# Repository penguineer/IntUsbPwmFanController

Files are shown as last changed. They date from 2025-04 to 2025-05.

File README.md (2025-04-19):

# PWM Fan Controller with Internal USB connection

> Controller for PWM-based fans using the internal USB 2.0 header

I have an NVIDIA server GPU which relies on external fans and uses the
`nvidia-smi` cli to report its temperature. In addition, my mainboard
does not allow for fan speed control under
Linux.

As this is my workstation setup and I do not want the fans running at
full speed all the time, I needed a controller to set the fan speed from
software, which easily integrates into my case.

This controller is plugged into an internal USB 2.0 header and offers
the 4-pin PWM header to connect fans.

## License



This work is licensed under
a [Creative Commons Attribution-ShareAlike 4.0 International License](http://creativecommons.org/licenses/by-sa/4.0/).

BY: Stefan Haun (mail at tuxathome.de)

See [LICENSE.txt](LICENSE.txt) for details.

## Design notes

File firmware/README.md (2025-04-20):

# PWM Fan Controller with Internal USB connection - Firmware

> Firmware for the PWM Fan Controller

Please refer to the [project README](../README.md) for further information.

## API

The MCU pin assignment is as follows:

* `PA1` - SDA
* `PA2` - SCL
* `PA3` - PWM output
* `PA6` - Tachometer signal input
* `PA7` - `SLEEP#` input, active low

The firmware exposes an I2C API for the PWM Fan Controller with the following commands:

* `TWI_CMD_GET_ID` (read): Get the serial number of the ATtiny202 device. Returns the serial number as a 4-byte array.
* `TWI_CMD_SET_PWM` (write): Set the PWM value using an 1-byte parameter, where `0x00` is 0%, aka off, and `0xFF` is
  100%, aka full speed.
* `TWI_CMD_GET_TACHO` (read): Get the most recent tachometer measurement in RPM as a 2-byte array.

Pin `PA7` acts as a suspend pin. If the pin is pulled low, the firmware will enter a low-power mode. The firmware will
wake up when the pin is pulled high again.

## Architecture

The firmware is designed to run on
the [ATtiny202](https://ww1.microchip.com/downloads/en/DeviceDoc/ATtiny202-402-AVR-MCU-with-Core-Independent-Peripherals_and-picoPower-40001969A.pdf)
microcontroller. It uses the I2C protocol for communication with
an [FTDI201XS](https://www.mouser.de/datasheet/2/163/DS_FT201X-3173.pdf) host.

The code makes heavy use of interrupts and the event system to handle all required tasks on a small MCU, so that the
main loop solely consists of setup code.

### TWI handling

TWI communication is handled using the *ATtiny202 TWI*
peripheral with small RX and TX buffers for multibyte transfers. Depending on the command received, a matching handler
function is called.

### PWM generation

The PWM signal is generated using
the *ATtiny202 Timer/Counter TCA*.
The frequency is set to 25 kHz, according to the specifications for PC fans (c.f. [Noctua PWM specifications
white paper](https://noctua.at/pub/media/wysiwyg/Noctua_PWM_specifications_white_paper.pdf)).

### Tachometer measurement

The tachometer pulses are counted using the *ATtiny202 Timer/Counter TCB*.
Using the *Event System*, the TCB is configured to trigger on the rising edge of the tachometer signal on pin `PA6`.

The *ATtiny202 RTC* is configured to generate an interrupt once per second. The interrupt handler reads the TCB
counter value and resets it. The counter value is then converted to RPM and stored in a buffer, which can be read by the
TWI handler.

### Low-power mode handling

When the `SLEEP#` pin is pulled low, the firmware enters a low-power mode. The PWM signal is turned off and tachometer
measurements is disabled.

The firmware will wake up when the pin is pulled high again, re-setting the PWM duty cycle to the last set value and
re-enabling the tachometer measurement. Please note that the first two seconds of RMP measurement after waking up are
not accurate, as the FAN needs to spin up first and the measurement has been reset to zero.

## License

The firmware is licensed under the [MIT License](LICENSE.txt). See the [LICENSE.txt](LICENSE.txt) file for details.

© 2025 Stefan Haun and contributors

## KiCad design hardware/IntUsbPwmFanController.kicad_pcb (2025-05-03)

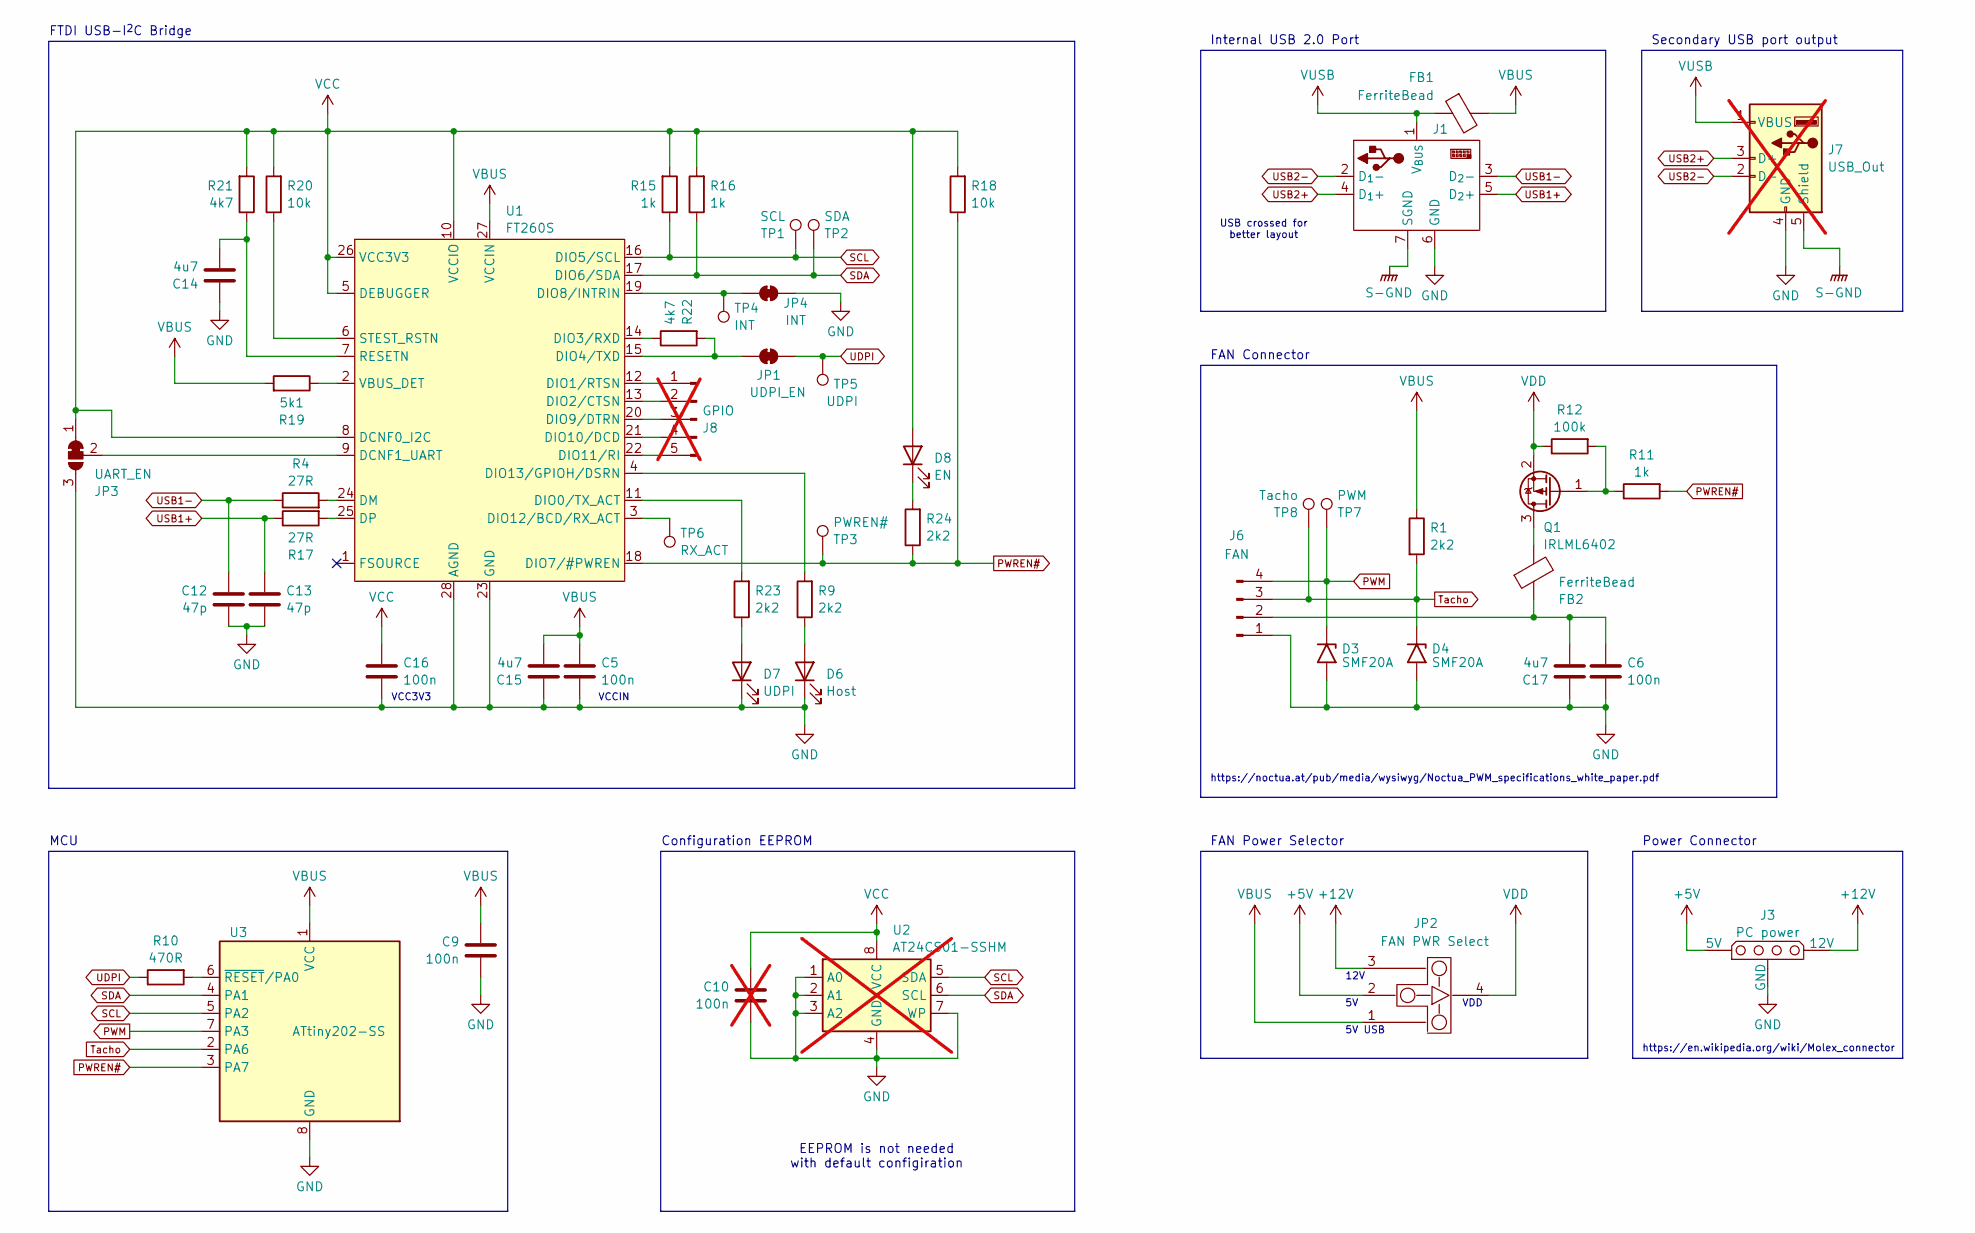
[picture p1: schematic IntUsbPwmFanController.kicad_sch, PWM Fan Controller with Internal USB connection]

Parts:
C5, C6, C9, C16: 100n; C_0603_1608Metric_Pad1.08x0.95mm_HandSolder; Mouser No 963-TMK107BJ104MA-T
C10: 100n; C_0603_1608Metric_Pad1.08x0.95mm_HandSolder; Mouser No 963-TMK107BJ104MA-T; not fitted
C12, C13: 47p; C_0603_1608Metric_Pad1.08x0.95mm_HandSolder; Mouser No 80-C0603C470K4HACTU
C14, C15, C17: 4u7; C_0603_1608Metric_Pad1.08x0.95mm_HandSolder; Mouser No 963-TMK107BJ104MA-T
D3, D4: SMF20A; D_SMF; LCSC C151295
D6: Host; LED_0603_1608Metric_Pad1.05x0.95mm_HandSolder; Mouser No 720-LTQ39GQ1S22515
D7: UDPI; LED_0603_1608Metric_Pad1.05x0.95mm_HandSolder; Mouser No 630-HSMC-C130
D8: EN; LED_0603_1608Metric_Pad1.05x0.95mm_HandSolder; Mouser No 720-LTQ39GQ1S22515
FB1, FB2: FerriteBead; R_0603_1608Metric_Pad0.98x0.95mm_HandSolder; Mouser No 81-BLM18SG221TZ1D
J1: Internal USB 2.0 Header Default
J3: PC power; Molex 8981 Vertical
J6: FAN; FanPinHeader_1x04_P2.54mm_Vertical
J7: USB_Out; USB_A_Molex_105057_Vertical; not fitted
J8: GPIO; PinHeader_1x05_P2.54mm_Vertical; not fitted
JP1: UDPI_EN; SolderJumper-2_P1.3mm_Bridged_RoundedPad1.0x1.5mm
JP2: FAN PWR Select; ThreeWayJumper
JP3: UART_EN; SolderJumper-3_P1.3mm_Bridged12_RoundedPad1.0x1.5mm
JP4: INT; SolderJumper-2_P1.3mm_Bridged_RoundedPad1.0x1.5mm
Q1: IRLML6402; SOT-23
R1, R9, R23, R24: 2k2; R_0603_1608Metric_Pad0.98x0.95mm_HandSolder
R4, R17: 27R; R_0603_1608Metric_Pad0.98x0.95mm_HandSolder
R10: 470R; R_0603_1608Metric_Pad0.98x0.95mm_HandSolder
R11, R15, R16: 1k; R_0603_1608Metric_Pad0.98x0.95mm_HandSolder
R12: 100k; R_0603_1608Metric_Pad0.98x0.95mm_HandSolder
R18, R20: 10k; R_0603_1608Metric_Pad0.98x0.95mm_HandSolder
R19: 5k1; R_0603_1608Metric_Pad0.98x0.95mm_HandSolder
R21, R22: 4k7; R_0603_1608Metric_Pad0.98x0.95mm_HandSolder
TP1: SCL; TestPoint_Pad_D1.0mm
TP2: SDA; TestPoint_Pad_D1.0mm
TP3: PWREN#; TestPoint_Pad_D1.0mm
TP4: INT; TestPoint_Pad_D1.0mm
TP5: UDPI; TestPoint_Pad_D1.0mm
TP6: RX_ACT; TestPoint_Pad_D1.0mm
TP7: PWM; TestPoint_Pad_D1.0mm
TP8: Tacho; TestPoint_Pad_D1.0mm
U1: FT260S; TSSOP-28_4.4x9.7mm_P0.65mm
U2: AT24CS01-SSHM; SOIC-8_3.9x4.9mm_P1.27mm; Mouser No 556-AT24CS01-SSHM-T; not fitted
U3: ATtiny202-SS; SOIC-8_3.9x4.9mm_P1.27mm

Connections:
+5V: J3.4 (5V), JP2.2 (OPT2)
+12V: J3.1 (12V), JP2.3 (OPT3)
GND: C5.2, C6.2, C9.2, C10.2, C12.2, C13.2, C14.1, C15.1, C16.2, C17.1, D3.2 (A2), D4.2 (A2), D6.1 (K), D7.1 (K), J1.6 (GND), J3.23 (GND), J6.1, J7.4 (GND), JP3.3 (B), JP4.2 (B), U1.23 (GND), U1.28 (AGND), U2.1 (A0), U2.2 (A1), U2.3 (A2), U2.4 (GND), U2.7 (WP), U3.8 (GND)
unnamed: D6.2 (A), R9.1
unnamed: D7.2 (A), R23.1
unnamed: D8.1 (K), R24.2
unnamed: C6.1, C17.2, FB2.1, J6.2
unnamed: J8.1, U1.12 (DIO1/RTSN)
unnamed: J8.2, U1.13 (DIO2/CTSN)
unnamed: J8.3, U1.20 (DIO9/DTRN)
unnamed: J8.4, U1.21 (DIO10/DCD)
unnamed: J8.5, U1.22 (DIO11/RI)
unnamed: JP1.1 (A), R22.2, U1.15 (DIO4/TXD)
unnamed: JP3.2 (C), U1.9 (DCNF1_UART)
unnamed: JP4.1 (A), TP4.1, U1.19 (DIO8/INTRIN)
unnamed: FB2.2, Q1.3 (D)
unnamed: Q1.1 (G), R11.1, R12.2
unnamed: R23.2, U1.11 (DIO0/TX_ACT)
unnamed: R22.1, U1.14 (DIO3/RXD)
unnamed: TP6.1, U1.3 (DIO12/BCD/RX_ACT)
unnamed: R9.2, U1.4 (DIO13/GPIOH/DSRN)
unnamed: R4.2, U1.24 (DM)
unnamed: R17.2, U1.25 (DP)
unnamed: C14.2, R21.1, U1.7 (RESETN)
unnamed: R20.1, U1.6 (STEST_RSTN)
unnamed: R19.1, U1.2 (VBUS_DET)
unnamed: R10.2, U3.6 (~RESET/PA0)
PWM: D3.1 (A1), J6.4, TP7.1, U3.7 (PA3)
PWREN#: R11.2, R18.1, R24.1, TP3.1, U1.18 (DIO7/#PWREN), U3.3 (PA7)
S-GND: J1.7 (SGND), J7.5 (Shield)
SCL: R15.1, TP1.1, U1.16 (DIO5/SCL), U2.5 (SDA), U3.5 (PA2)
SDA: R16.1, TP2.1, U1.17 (DIO6/SDA), U2.6 (SCL), U3.4 (PA1)
Tacho: D4.1 (A1), J6.3, R1.2, TP8.1, U3.2 (PA6)
UDPI: JP1.2 (B), R10.1, TP5.1
USB1+: C13.1, J1.5 (D_{2}+), R17.1
USB1-: C12.1, J1.3 (D_{2}-), R4.1
USB2+: J1.4 (D_{1}+), J7.3 (D+)
USB2-: J1.2 (D_{1}-), J7.2 (D-)
VBUS: C5.1, C9.1, C15.2, FB1.2, JP2.1 (OPT1), R1.1, R19.2, U1.27 (VCCIN), U3.1 (VCC)
VCC: C10.1, C16.1, D8.2 (A), JP3.1 (A), R15.2, R16.2, R18.2, R20.2, R21.2, U1.5 (DEBUGGER), U1.8 (DCNF0_I2C), U1.10 (VCCIO), U1.26 (VCC3V3), U2.8 (VCC)
VDD: JP2.4 (SEL), Q1.2 (S), R12.1
VUSB: FB1.1, J1.1 (V_{BUS}), J7.1 (VBUS)

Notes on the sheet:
Secondary USB port output
https://en.wikipedia.org/wiki/Molex_connector
Power Connector
USB crossed for better layout
EEPROM is not needed with default configiration
VDD
VCCIN
Internal USB 2.0 Port
5V USB
FAN Connector
12V
MCU
FAN Power Selector
Configuration EEPROM
https://noctua.at/pub/media/wysiwyg/Noctua_PWM_specifications_white_paper.pdf
FTDI USB-I^{2}C Bridge
VCC3V3

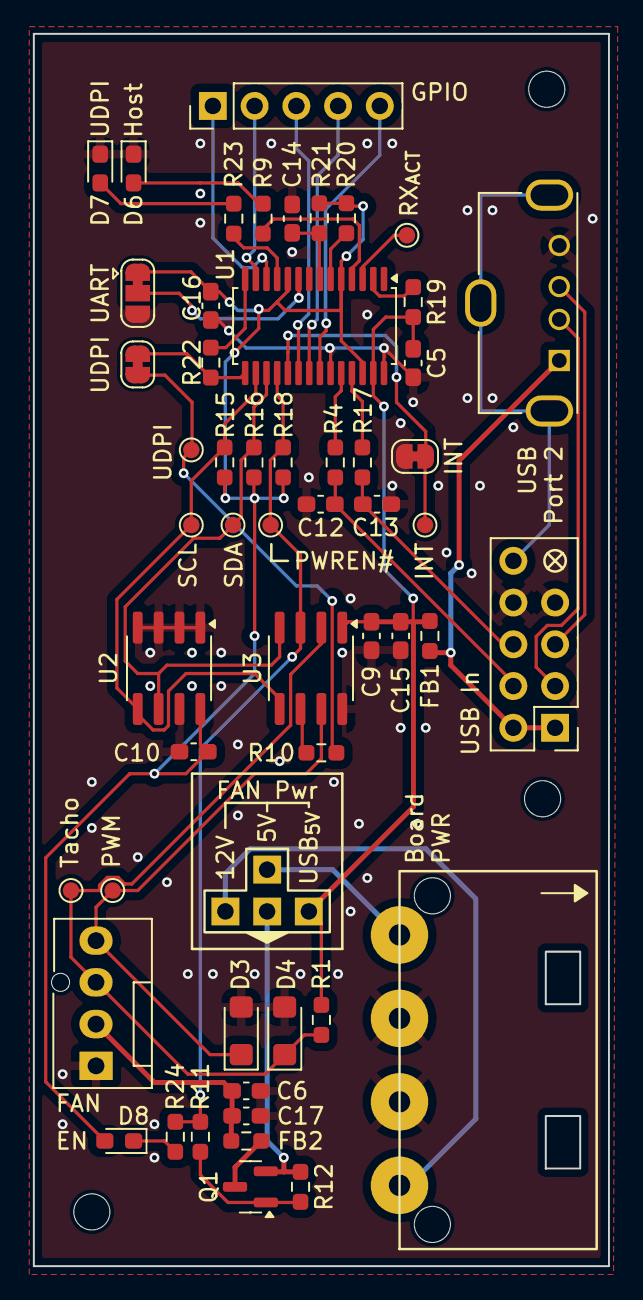
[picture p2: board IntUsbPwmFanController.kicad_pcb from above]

Board: 2 copper layers, 35.0 x 75.0 mm, 54 parts (0 on the bottom side), 42 nets.

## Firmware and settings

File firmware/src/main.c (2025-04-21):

#include <stddef.h>
#include <avr/io.h>
#include <avr/interrupt.h>
#include <avr/sleep.h>

#define TWI_SLAVE_ADDRESS 0x42

/* TWI command "Get ID"
 *
 * This command returns the unique chip ID (4 bytes).
 */
#define TWI_CMD_GET_ID    0x01
/* TWI command "Set PWM"
 *
 * This command sets the target PWM value (1 byte).
 */
#define TWI_CMD_SET_PWM   0x02
/* TWI command "Get Tacho"
 *
 * This command returns the most recent completed tachometer measurement (2 bytes).
 *
 * Please note that there is a delay between setting the PWM value and retrieving a matching tachometer measurement.
 */
#define TWI_CMD_GET_TACHO 0x03

/***** Global variables *****/

uint8_t pwm_target = 0; // Target PWM value
uint16_t tacho_rpm = 0; // Most recent tacho measurement

/***** PWM *****/

// Assumes a prescaler of 8 and a frequency of 25 kHz
#define PWM_PREBUF ((F_CPU / (8 * 25000)) - 1)

void TCA_init_pwm(void) {
    // Configure PA3 as output
    PORTA.DIRSET = PIN3_bm; // Set PA3 as output

    // TCA0 WO[1] routes to PA3

    // Set TCA0 to single-slope PWM mode
    TCA0.SINGLE.CTRLB = TCA_SINGLE_WGMODE_SINGLESLOPE_gc | TCA_SINGLE_CMP1EN_bm; // Enable WO1 (PA3)

    // Set the period
    TCA0.SINGLE.PER = PWM_PREBUF;

    // Set the compare value for 0% duty cycle
    TCA0.SINGLE.CMP1 = 0; // 0% duty cycle

    // Enable the TCA0 clock with a prescaler of 8
    TCA0.SINGLE.CTRLA = TCA_SINGLE_CLKSEL_DIV8_gc | TCA_SINGLE_ENABLE_bm;
}

void update_target_pwm(const uint8_t duty_cycle_param) {
    // Store the setting
    pwm_target = duty_cycle_param;

    // Perform the calculation in a 32-bit space to avoid wrapping/clipping
    const uint32_t temp = (uint32_t) PWM_PREBUF * duty_cycle_param;
    // Scale back to the correct range
    TCA0.SINGLE.CMP1 = temp >> 8;
}

/***** Tacho *****/

void PA6_enable_edge_sensing(void) {
    // Enable sensing on rising edge
    PORTA.PIN6CTRL = PORT_ISC_RISING_gc;
}

void PA6_disable_edge_sensing(void) {
    // Disable sensing
    PORTA.PIN6CTRL = 0;
}

void TCB_init_tacho_counter(void) {
    // Configure PA6 as input
    PORTA.DIRCLR = PIN6_bm; // Set PA6 as input
    PA6_enable_edge_sensing();

    // Configure Event System to route PA6 to TCB0
    EVSYS.ASYNCCH0 = EVSYS_ASYNCCH0_PORTA_PIN6_gc; // Pin PA6
    EVSYS.ASYNCUSER0 = EVSYS_ASYNCUSER0_ASYNCCH0_gc; // route to TCB0

    // Configure TCB0 in event counting mode
    TCB0.CTRLA = TCB_CLKSEL_CLKDIV1_gc | TCB_ENABLE_bm; // Enable TCB0 with no prescaler
    TCB0.CTRLB = TCB_CNTMODE_FRQ_gc; // Frequency measurement mode (event counting)

    // Clear the counter
    TCB0.CNT = 0;
}

uint16_t TCB_get_and_reset_count(void) {
    // Disable edge sensing to prevent race conditions
    PA6_disable_edge_sensing();

    // Read the current count
    const uint16_t count = TCB0.CNT;
    // Clear the counter
    TCB0.CNT = 0;

    // Enable edge sensing
    PA6_enable_edge_sensing();

    // Return the current counter value
    return count;
}

void RTC_init(void) {
    // Wait until RTC is not busy
    while (RTC.STATUS > 0)
        /* busy wait */;

    // Initialize RTC function
    // (ATtiny 202 Datasheet 22.3)

    // Configure RTC clock source to use the 1 kHz internal oscillator
    RTC.CLKSEL = RTC_CLKSEL_INT1K_gc;

    // Set the period to 1000 (1 second with 1 kHz clock)
    RTC.PER = 1000;

    // Enable the overflow (OVF) interrupt
    RTC.INTCTRL = RTC_OVF_bm;

    // Configure the prescaler to divide by 1 and enable the RTC
    RTC.CTRLA = RTC_PRESCALER_DIV1_gc | RTC_RTCEN_bm;

    // Clear any existing interrupt flags
    RTC.INTFLAGS = RTC_OVF_bm;
}

void RTC_reset(void) {
    // Wait until RTC is not busy
    while (RTC.STATUS > 0)
        /* busy wait */;

    // Reset the RTC counter
    RTC.CNT = 0;
}

ISR(RTC_CNT_vect) {
    // We are reading the TCB0 counter once per second
    const uint16_t revolutions_per_second = TCB_get_and_reset_count();

    // Convert to RPM according to specification
    // See https://noctua.at/pub/media/wysiwyg/Noctua_PWM_specifications_white_paper.pdf for details.
    // There are two pulses per revolution.
    const uint16_t rpm = revolutions_per_second * 60 >> 1;

    // Atomic store
    cli();
    tacho_rpm = rpm;
    sei();

    // Clear the overflow interrupt flag
    RTC.INTFLAGS = RTC_OVF_bm;
}

/***** TWI Core *****/

void TWI_slave_init(void) {
    // Configure SCL (PA2) and SDA (PA1) as inputs
    PORTA.DIRCLR = PIN2_bm | PIN1_bm; // leaves other pins unchanged

    // Enable internal pull-ups on SCL (PA2) and SDA (PA1)
    PORTA.PIN2CTRL |= PORT_PULLUPEN_bm;
    PORTA.PIN1CTRL |= PORT_PULLUPEN_bm;

    // Set the slave address
    TWI0.SADDR = TWI_SLAVE_ADDRESS << 1; // Shifted left by 1 for 7-bit addressing

    // Enable TWI Slave, enable stop interrupt, and enable data interrupt
    TWI0.SCTRLA = TWI_ENABLE_bm | TWI_PIEN_bm | TWI_DIEN_bm;

    // Clear any pending interrupts
    TWI0.SSTATUS = TWI_APIF_bm | TWI_DIF_bm;
}

#define TWI_BUFFER_SIZE 4

static uint8_t tx_buffer[TWI_BUFFER_SIZE]; // Buffer for data to send
static uint8_t tx_index = 0; // Current index in the buffer
static uint8_t tx_length = 0; // Number of bytes to send

void TWI_prepare_response(const uint8_t *data, const uint8_t length) {
    if (data != NULL) {
        // Copy data to the transmission buffer
        tx_length = (length > TWI_BUFFER_SIZE) ? TWI_BUFFER_SIZE : length;
        // This loop is likely to be unrolled by the compiler
        for (uint8_t i = 0; i < tx_length; i++) {
            tx_buffer[i] = data[i];
        }
    }

    // Reset index for new transmission
    tx_index = 0;
}

void TWI_handle_master_command(uint8_t, const uint8_t *, uint8_t);

#define RX_BUFFER_SIZE 2

static uint8_t rx_buffer[RX_BUFFER_SIZE]; // Buffer for received data
static uint8_t rx_index = 0; // Current index in the buffer

ISR(TWI0_TWIS_vect) {
    if (TWI0.SSTATUS & TWI_APIF_bm) {
        // Address or Stop condition interrupt
        if (TWI0.SSTATUS & TWI_AP_bm) {
            // Address match
            tx_index = 0; // Reset index on new transaction
        } else {
            // STOP condition detected
            if (rx_index > 0) {
                // Process received data
                // Note that rx_index has already been incremented and points to the next position in the buffer,
                // thus represents the data length.
                TWI_handle_master_command(rx_buffer[0], &rx_buffer[1], rx_index);
            }
            rx_index = 0; // Reset receive buffer index
        }
        TWI0.SSTATUS |= TWI_APIF_bm; // Clear interrupt flag
    }

    if (TWI0.SSTATUS & TWI_DIF_bm) {
        // Data interrupt
        if (TWI0.SSTATUS & TWI_DIR_bm) {
            // Master is reading (DIR = 1)
            if (tx_index < tx_length) {
                // Send next byte
                TWI0.SDATA = tx_buffer[tx_index++];
            } else {
                // Send NACK to indicate no more data
                TWI0.SCTRLB |= TWI_ACKACT_bm;
            }
        } else {
            // Master is writing (DIR = 0)
            if (rx_index < RX_BUFFER_SIZE) {
                // Store received data in the buffer
                rx_buffer[rx_index++] = TWI0.SDATA;
            } else {
                // Buffer full, send NACK
                TWI0.SCTRLB |= TWI_ACKACT_bm;
            }
        }
        TWI0.SSTATUS |= TWI_DIF_bm; // Clear interrupt flag
    }
}

/***** TWI Slave Communication *****/

uint32_t get_chip_id(void) {
    // Access the unique serial number from the SIGROW memory space
    const uint32_t chip_id = (uint32_t) SIGROW.SERNUM0 << 24 |
                             (uint32_t) SIGROW.SERNUM1 << 16 |
                             (uint32_t) SIGROW.SERNUM2 << 8 |
                             (uint32_t) SIGROW.SERNUM3;
    return chip_id;
}

void TWI_handle_master_command(const uint8_t command, const uint8_t *data, const uint8_t data_length) {
    switch (command) {
        case TWI_CMD_GET_ID: {
            const uint32_t chip_id = get_chip_id();
            TWI_prepare_response((const uint8_t *) &chip_id, sizeof(chip_id));
            break;
        }
        case TWI_CMD_SET_PWM:
            if (data_length == 1) {
                const uint8_t pwm_target_param = data[0];
                update_target_pwm(pwm_target_param);
                // no response
                TWI_prepare_response(NULL, 0);
            }
            break;
        case TWI_CMD_GET_TACHO:
            // Atomic access
            cli();
            const uint16_t rpm = tacho_rpm;
            sei();
            TWI_prepare_response((const uint8_t *) &rpm, sizeof(rpm));
            break;
        default:
            // no data
            TWI_prepare_response(NULL, 0);
            break;
    }
}

/***** Sleep Mode *****/

void SLEEP_init(void) {
    // Configure PA7 as input
    PORTA.DIRCLR = PIN7_bm;

    // Enable interrupt on both edges with pull-up
    PORTA.PIN7CTRL = PORT_ISC_BOTHEDGES_gc | PORT_PULLUPEN_bm;
}

ISR(PORTA_PORT_vect) {
    // ISR(PORTA_PORT_vect) handles interrupts on PA7, which is configured for both edge detection.
    // This ISR is not triggered by PA6, as PA6 is configured for event routing via the Event System
    // and does not generate pin interrupts.

    if (PORTA.INTFLAGS & PIN7_bm) {
        if (PORTA.IN & PIN7_bm) {
            // Rising edge: Enter sleep mode

            // Set PWM to 0%
            update_target_pwm(0);
            // Stop tachometer calculations
            PA6_disable_edge_sensing();
            // Set sleep mode
            set_sleep_mode(SLEEP_MODE_STANDBY);
            sleep_enable();
            // Enter sleep mode
            sleep_cpu();
            // Disable sleep after waking up
            sleep_disable();
        } else {
            // Falling edge: Wake up and restore state

            // Restore PWM duty cycle
            update_target_pwm(pwm_target);

            // Reset and resume tachometer calculation
            TCB_get_and_reset_count();
            RTC_reset();
            PA6_enable_edge_sensing();
        }
        // Clear interrupt flag
        PORTA.INTFLAGS = PIN7_bm;
    }
}

/***** Main *****/

void set_clock_to_20MHz(void) {
    // Set the main clock source to the 20 MHz internal oscillator
    _PROTECTED_WRITE(CLKCTRL.MCLKCTRLA, CLKCTRL_CLKSEL_OSC20M_gc);

    // Set the pre-scaler to divide by 2 (20 MHz / 2 = 10 MHz)
    _PROTECTED_WRITE(CLKCTRL.MCLKCTRLB, CLKCTRL_PDIV_2X_gc | CLKCTRL_PEN_bm);
}

int main(void) {
    set_clock_to_20MHz();
    TWI_slave_init();
    TCA_init_pwm();
    TCB_init_tacho_counter();
    RTC_init();
    SLEEP_init();

    // ReSharper disable once CppDFAEndlessLoop
    for (;;);
}

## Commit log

2025-04-19 Add gitignore for KiCad project
2025-04-19 First draft of the schematic
    [IntUsbPwmFanController.kicad_pcb, IntUsbPwmFanController.kicad_sch]
2025-04-20 Add a draft implementation of PWM
2025-04-20 Re-assign MCU pins after firmware considerations
    [IntUsbPwmFanController.kicad_sch]
2025-04-20 Minor fixes to the code
    [main.c]
2025-04-20 Change how tacho measurement is disabled to avoid unintended ISR calls
    [main.c]
2025-04-20 Fix data length calculation for the receive buffer
    [main.c]
2025-04-21 Replace FT201XS (I2C slave) with FT260S (I2C master)
    [IntUsbPwmFanController.kicad_sch]
2025-04-21 Invert SLEEP signal interpretation for PWREN#
    Instead of SLEEP, the signal PWREN# is now provided, which is inverted.
    [main.c]
2025-04-21 Add (optional) configuration EEPROM
    Since it has a very small footprint and optinal GPIO headers are also
    available, add a configuration EEPROM to the design.
    [IntUsbPwmFanController.kicad_sch]
2025-04-21 Fix the solder jumpers
    [IntUsbPwmFanController.kicad_sch]
2025-04-21 Add Symbol and Footprint for the 3-way jumper selection
2025-04-21 Use new symbol for the 3-way jumper
    [IntUsbPwmFanController.kicad_sch]
2025-04-21 Improve fan connector filtering
    [IntUsbPwmFanController.kicad_sch]
2025-04-21 Fix FT260S decoupling cap assignment
    C16 was accidentally assigned to vbus, when it should have been VCC3V3.
    [IntUsbPwmFanController.kicad_sch]
2025-04-21 Add symbol and footprint for Molex 8981 Power Connector
2025-04-21 Use the correct Molex connector symbol/footprint
    [IntUsbPwmFanController.kicad_sch]
2025-04-21 Add symbol/footprint for the USB 2.0 header
2025-04-21 Use correct symbol/footprint for the USB 2.0 header
    [IntUsbPwmFanController.kicad_sch]
2025-04-23 Add a PCB layout draft
    [IntUsbPwmFanController.kicad_pcb, IntUsbPwmFanController.kicad_sch]
2025-04-23 Add a footprint for an internal USB 2.0 socket
2025-04-23 Change default USB 2.0 header footprint to default socket
2025-04-23 Adjust schematic and PCB to the new footprint
    [IntUsbPwmFanController.kicad_pcb, IntUsbPwmFanController.kicad_sch]
2025-05-03 Add a pinheader USB 2.0 connector
2025-05-03 Switch to a pinheader for the USB connector
    [IntUsbPwmFanController.kicad_pcb, IntUsbPwmFanController.kicad_sch]
2025-06-13 Add Labels and CC to PCB
